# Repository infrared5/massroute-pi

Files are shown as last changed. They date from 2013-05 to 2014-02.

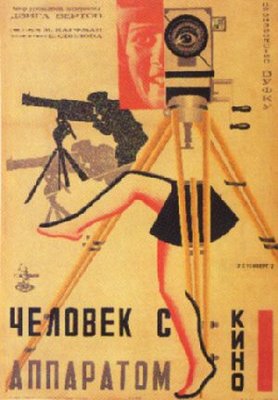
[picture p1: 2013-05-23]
Art/Research/Constructivism/c3.jpg

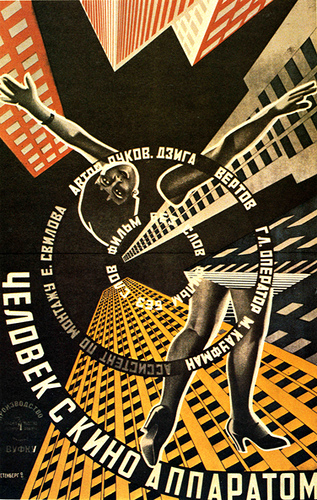
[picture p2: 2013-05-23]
Art/Research/Constructivism/Ev_timeline_RussianConstructivism_constructivism.jpg.jpeg

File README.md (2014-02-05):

Introduction
---
> An exploration of real-time bus data aggregation and display using Raspberry Pi

###Schematic

MassROUTE-Pi schematic

###Development

```
$> mkvirtualenv massroute
$> pip install -r requirements.txt
```

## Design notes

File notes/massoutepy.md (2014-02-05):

Specs
---

* Raspbian Wheezy.
* preinstalled RPi.GPIO python library.
* '595 Shift Registers (x2)
* LED 20mA ? (x14)
* 100ohm Resisters (x14)

### Circuit
3.3 V
limit LED's to 2.5V at 20mA
R = .8 / .02 = 40ohm
Using 100ohm.

### Transistor - NOT USED
Using transistor to transfer power to the circuit through digital write on GPIO pin instead of kust supplying power to the Raspberry Pi unit.

Transistor = NPN 2N2222

**R = V / I**

* Collector =  x = 3.3V / 6mA = 3.3 / .06 = 55 (rounded to 100ohm)
* Base = x = 3.3v / 1.2mA = 3.3 / .0012 = 2750 (used 4700ohm)
* Emitter = x = 3.3v / 17mA = 3.3 / .017 = 194 (used 220ohm)

Boot
---
Added massroute.sh to /etc/init.d : [http://www.debian-administration.org/articles/28](http://www.debian-administration.org/articles/28)

	$> sudo /etc/init.d/massroute stop

TRIED:

Added script to /etc/rc.local:

	(sleep 10;sh ~/Desktop/massroutepy/init.sh)&
	
:NOT WORK

Cron
---
Created cron to run at 6am every morning. This allowed for the system to start its program again at 6am. It should have been properly shutdown by itself by checking the scheduler during execution.

	$> crontab -e
	$> 00 06 * * * sudo sh /home/pi/Desktop/massroute-py/init.sh
	$> sudo /etc/init.d/cron restart

Articles
---
Raw: [https://sites.google.com/site/semilleroadt/raspberry-pi-tutorials/gpio](https://sites.google.com/site/semilleroadt/raspberry-pi-tutorials/gpio)

RPi: [https://code.google.com/p/raspberry-gpio-python/wiki/BasicUsage](https://code.google.com/p/raspberry-gpio-python/wiki/BasicUsage)

[http://openmicros.org/index.php/articles/94-ciseco-product-documentation/raspberry-pi/217-getting-started-with-raspberry-pi-gpio-and-python](http://openmicros.org/index.php/articles/94-ciseco-product-documentation/raspberry-pi/217-getting-started-with-raspberry-pi-gpio-and-python)

**Error:**
RPi.GPIO.ModeNotSetException: Please set pin numbering mode using GPIO.setmode(GPIO.BOARD) or GPIO.setmode(GPIO.BCM)

**Resolution:** GPIO.setmode(GPIO.BCM)

Communication with RESTful service
---
Uses [requests](http://docs.python-requests.org/en/latest/user/quickstart/) python library:
http://docs.python-requests.org/en/latest/user/quickstart/

cloned and setup: http://docs.python-requests.org/en/latest/user/install/#install

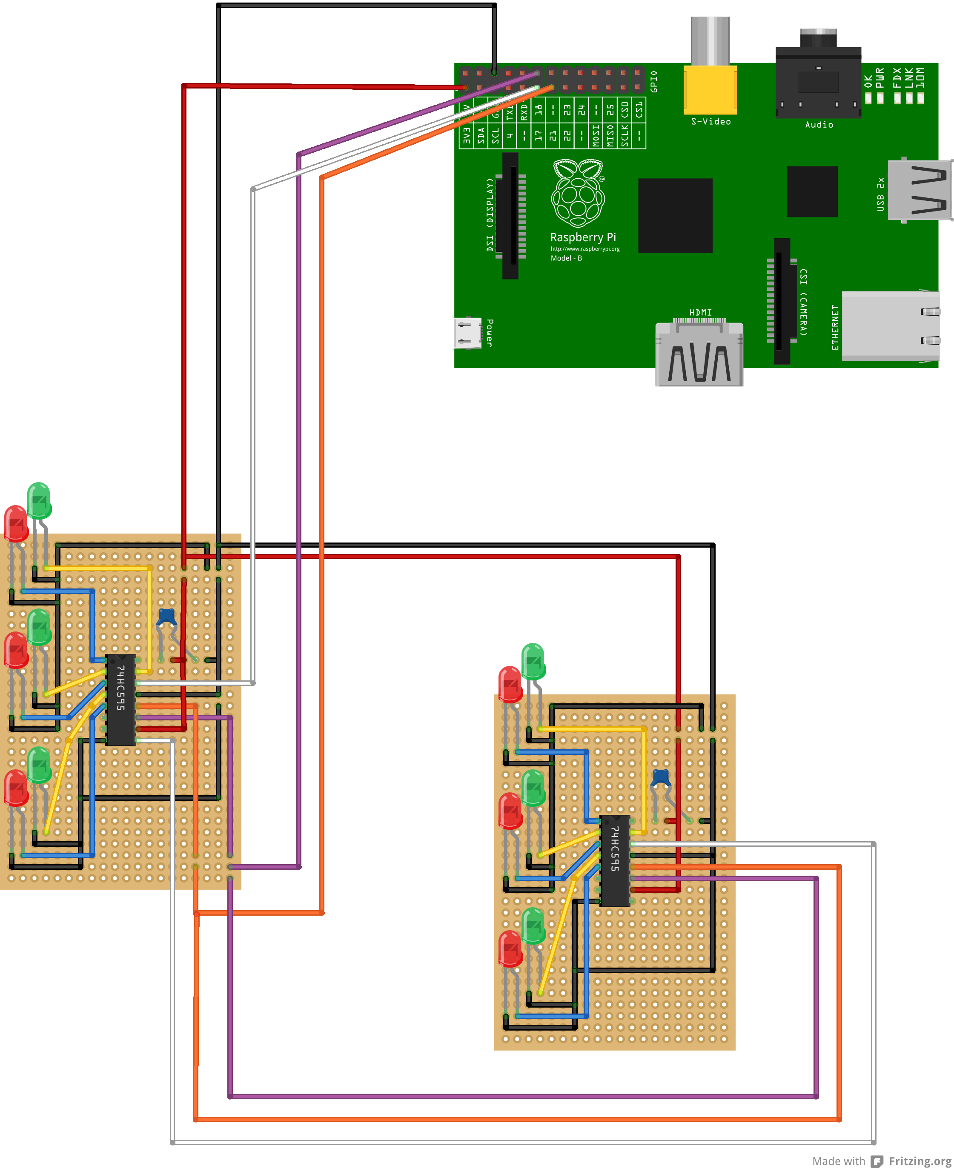
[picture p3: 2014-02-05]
notes/massroutepy_schematic.png

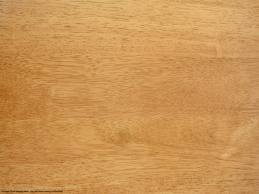
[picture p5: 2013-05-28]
Art/PSD/Assets/Wood.jpeg

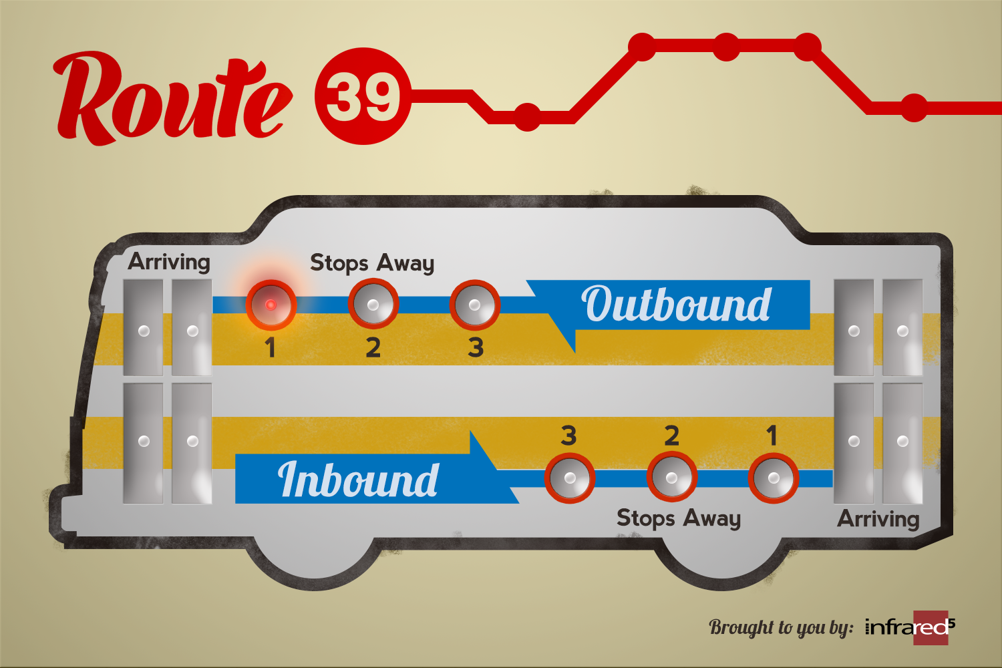
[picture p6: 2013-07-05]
Art/Review/Massroute-Sign.png

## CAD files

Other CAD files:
Art/Models/Store_Preview.blend
Art/Models/Store_Preview_noframe.blend

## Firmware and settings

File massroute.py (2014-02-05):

import os
import os.path
import logging
import RPi.GPIO as GPIO

from sys import argv
from time import sleep

from app.board import Board
from app.service.service import Service
from app.util.scheduler import Scheduler
from app.request.factory import StopRequestFactory
from app.program import Program
from app.component.modifier.blinker import blinker_pool

script, task = argv

cwd = os.getcwd()
log_dir = '{root}/{dir}'.format(root=cwd, dir='log')
if not os.path.exists(log_dir):
  os.mkdir(log_dir)
log_file = '{dir}/{filename}'.format(dir=log_dir, filename='massroute.log')
print 'massroute log file: %r' % log_file

format = '%(asctime)s %(name)s [%(levelname)s]: %(message)s'
logging.basicConfig(level=logging.DEBUG, format=format)
formatter = logging.Formatter(format)

# console = logging.StreamHandler()
# console.setLevel(logging.DEBUG)
# console.setFormatter(formatter)
# logging.getLogger('').addHandler(console)
fileh = logging.FileHandler(log_file)
fileh.setLevel(logging.ERROR)
fileh.setFormatter(formatter)
logging.getLogger('').addHandler(fileh)

logger = logging.getLogger(__name__)

SCHEDULE_START = 6 # 6am
SCHEDULE_END = 22 # 10pm
BASE_URL = 'http://68.169.43.76:3001'
PREDICTION_URI = 'routes/39/destinations/39_1_var1/stops'

def main():
  try:
    GPIO.cleanup()
    board = Board()
    service = Service(BASE_URL, PREDICTION_URI)
    scheduler = Scheduler(SCHEDULE_START, SCHEDULE_END)

    program = Program(board, scheduler)
    program.set_service(service)

    if task == 'start':
      program.enqueue(StopRequestFactory(board.shifter))
      program.start()
    elif task == 'stop':
      program.stop()
    elif task == 'web':
      service.access()
    elif task == 'blink':
      board.blinker_test()
    elif task == 'error':
      board.run_resource_error()
    else:
      logger.warning('Task not found: %r' % task)

  except KeyboardInterrupt:
    blinker_pool.drain()
    if 'board' in locals():
      board.run_shutdown_seq()
  except Exception, e:
    logger.warning('Could not properly run %s: %r' % (task, e))
    if 'board' in locals():
      board.run_resource_error()

if __name__ == '__main__':
  main()

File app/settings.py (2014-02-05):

DATA_PIN = 17
LATCH_PIN = 22
CLOCK_PIN = 18

NUM_REGISTERS = 2

INBOUND_STOP_1 = 1129 # Centre St. & Seaverns
INBOUND_STOP_2 = 1128 # South St. & Sedgwick
INBOUND_STOP_3 = 1938 # South St @ Carolina Ave

OUTBOUND_STOP_1 = 11164 # Centre St. & Burroughs
OUTBOUND_STOP_2 = 1164  # Centre St. & Myrtle
OUTBOUND_STOP_3 = 1161  # Centre St. & Lochstead

INBOUND_STOP_1_PIN = 4
INBOUND_STOP_1_PIN_CLUSTER = (0,1,2,3)
INBOUND_STOP_2_PIN = 5
INBOUND_STOP_3_PIN = 6

OUTBOUND_STOP_1_PIN = 9
OUTBOUND_STOP_1_PIN_CLUSTER = (10,11,12,13)
OUTBOUND_STOP_2_PIN = 8
OUTBOUND_STOP_3_PIN = 7

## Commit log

2013-04-29 update for device state features and terminology explanations for clarity on NodeJS service and MAssRoute proxy.
2013-04-29 tests and implementation for device-state and unavailablity features.
2013-04-29 unit tests on switch-module.
2013-04-30 finish unit tests for switchModule to pass on features for device on/off.
2013-05-01 simple driver set up with switch.
2013-05-01 simple driver to test GPIO.
2013-05-01 logging in switch-module
2013-05-06 tests for predictions. new module generators for direction and bi-color-led.
2013-05-12 changes for driver and shifted bi-color modules.
2013-05-13 reorganization of composition to massroute-driver for clearer separation of module factory responsibilities.
2013-05-16 gpio led_module test. update to shifter module to delay on start delegate.
2013-07-24 Updates to sign concept
    [Store_Preview_noframe.blend]
2013-10-09 dumpof python development.
    [massroutepy.fzz]
